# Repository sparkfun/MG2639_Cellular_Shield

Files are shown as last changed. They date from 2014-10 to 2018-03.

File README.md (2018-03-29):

**Note:Retired Product**
This product has been retired from our catalog and is no longer for sale. This page is made available for those looking for datasheets and the simply curious.

SparkFun MG2639 Cellular Shield
=========================

SparkFun MG2639 Cellular Shield (https://www.sparkfun.com/products/13120)

[*SparkFun MG2639 Cellular Shield (CEL-13120)*](https://www.sparkfun.com/products/13120)

The SparkFun MG2639 Cellular shield is an Arduino compatible shield that gives the user access to the MG2639_V3 GSM+GPS module. The module is capable of accquiring a GPS location as well as communication with GSM networks all over the world. Phonecalls can be made, texts sent, and data pushed to and read from web pages. All the supporting circuitry is provided including translation from 2.8V of the module to a user selectable 3.3V or 5V.

The main interface is two software serial ports.

Power can be provided either from the Arduino board's VIN or from an external battery such as a lithium polymer.

Repository Contents
-------------------

* **/Firmware** - Example sketches that work without the Arduino library.
* **/Hardware** - Schematic and PCB layout for the shield. Also includes an eagle library containing the various custom footprints for this shield. Specifically the MG2639 footprint.
* **/Documentation** - The AT command set, hardware guide, and various other datasheets.
* **/Libraries** - The SparkFun MG2639 Cellular Shield library.
* **/Production** - Production panel files.
* **[Hookup Guide](https://learn.sparkfun.com/tutorials/retired---mg2639-cellular-shield-hookup-guide)** - To get started using the MG2639 Cellular Shield, check out our tutorial!

License Information
-------------------
The hardware is released under [CERN Open Hardware License 1.2](http://www.ohwr.org/attachments/2388/cern_ohl_v_1_2.txt).
The code is beerware; if you see me (or any other SparkFun employee) at the local, and you've found our code helpful, please buy us a round!

Distributed as-is; no warranty is given.

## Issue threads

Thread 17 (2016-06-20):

Arduino 1.6.7 warning

i-make-robots, 2016-06-20:
WARNING: Category '' in library SparkFun MG2639 CellShield is not valid. Setting to 'Uncategorized'

couilloux, 2016-09-17:
I have the same issue when I try the simple MG2639_GetInfo.

Any suggestion?

loricrotser, 2018-03-29:
Hello!

Since we have retired this product, I'm closing this issue. If you still need help with this product, you can also check in our forums [here](https://forum.sparkfun.com/).

Please do let us know if you have any more questions.

Thank you!

Closed 2018-03-29.

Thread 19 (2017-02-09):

HTTP REQUEST

n3mu, 2017-02-09:
So I try to edit the sample codes to " GET /test.php?fn=test HTTP/1.1\nHost: mysite.com\n\n"
It runs but it doesn't pass the 'fn' and I also try POST with HTTP headers and again it doesn't work, Anyone who have try to do HTTTP request before?

loricrotser, 2018-03-29:
Hello!

Since we have retired this product, I'm closing this issue. If you still need help with this product, you can also check in our forums [here](https://forum.sparkfun.com/).

Please do let us know if you have any more questions.

Thank you!

Closed 2018-03-29.

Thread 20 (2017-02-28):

BUG: Missing "return"

tatobari, 2017-02-28:
Line 108 of `MG2639_Cellular_Shield/Libraries/Arduino/src/SFE_MG2639_CellShield.cpp` should be:

`return begin(TARGET_BAUD_RATE);`

Instead of:

`begin(TARGET_BAUD_RATE);`

Otherwise, you can't know if the communication with the shield was successful because `0` is returned if nothing is specified.

loricrotser, 2018-03-29:
Hello!

Since we have retired this product, I'm closing this issue. If you still need help with this product, you can also check in our forums [here](https://forum.sparkfun.com/).

Please do let us know if you have any more questions.

Thank you!

Closed 2018-03-29.

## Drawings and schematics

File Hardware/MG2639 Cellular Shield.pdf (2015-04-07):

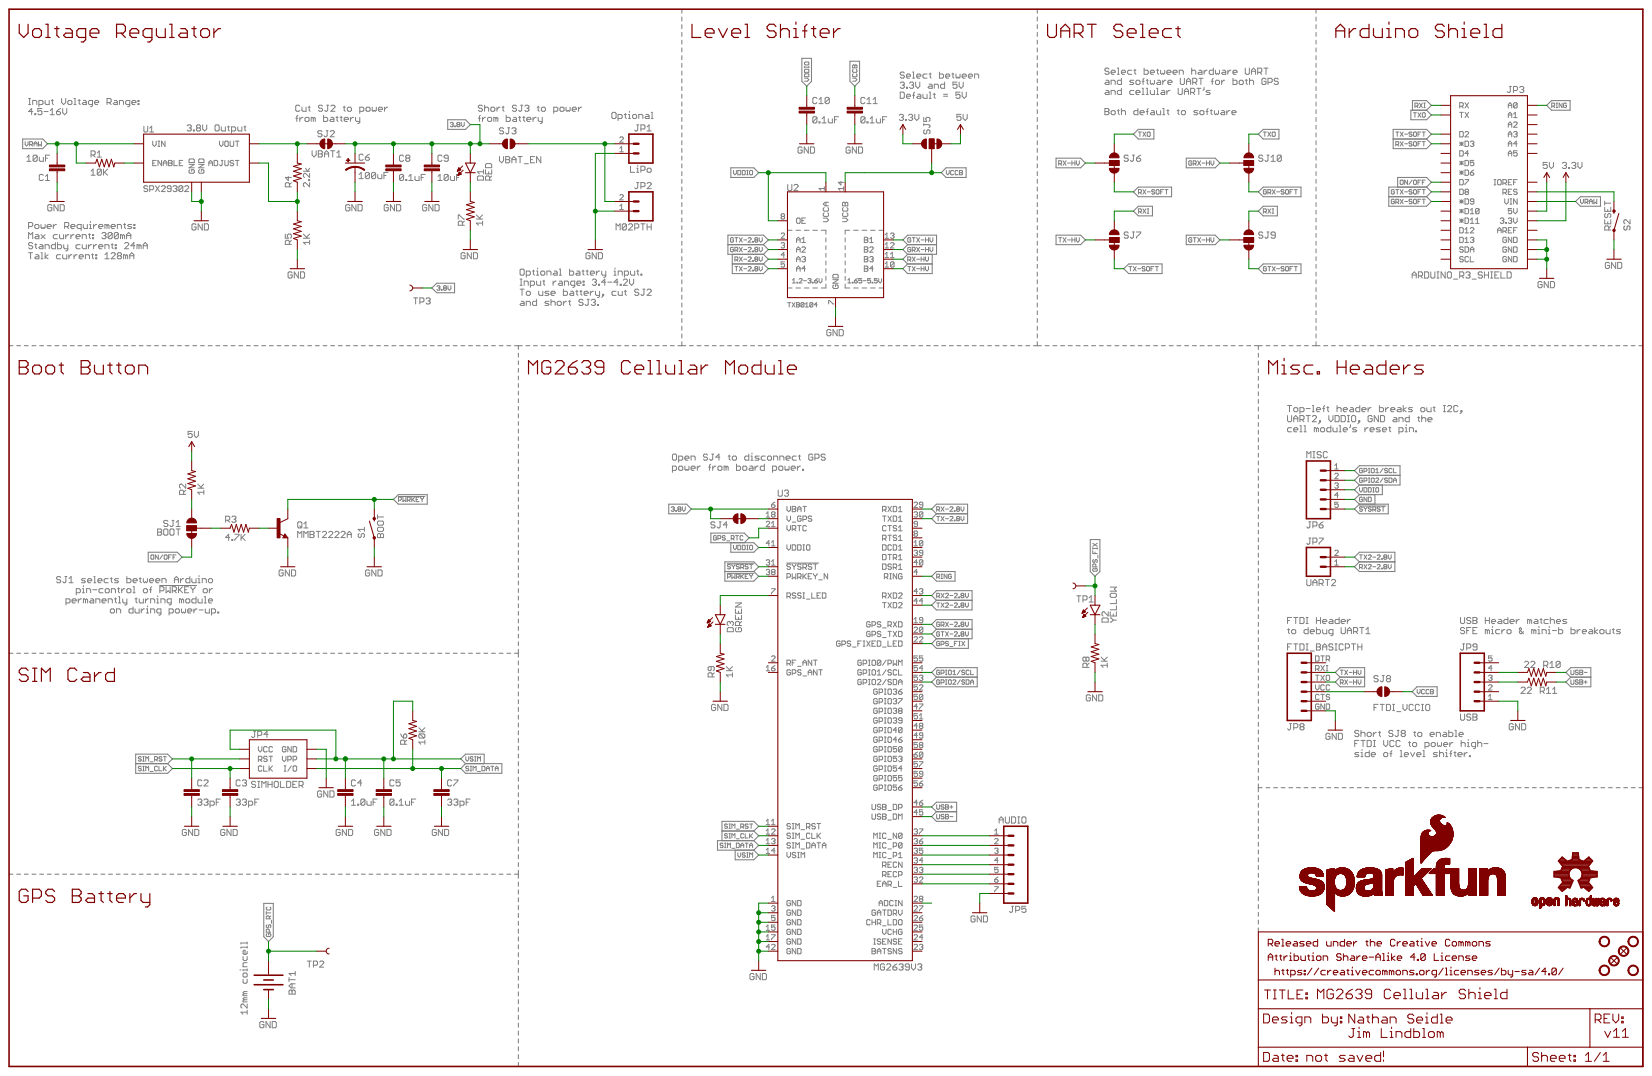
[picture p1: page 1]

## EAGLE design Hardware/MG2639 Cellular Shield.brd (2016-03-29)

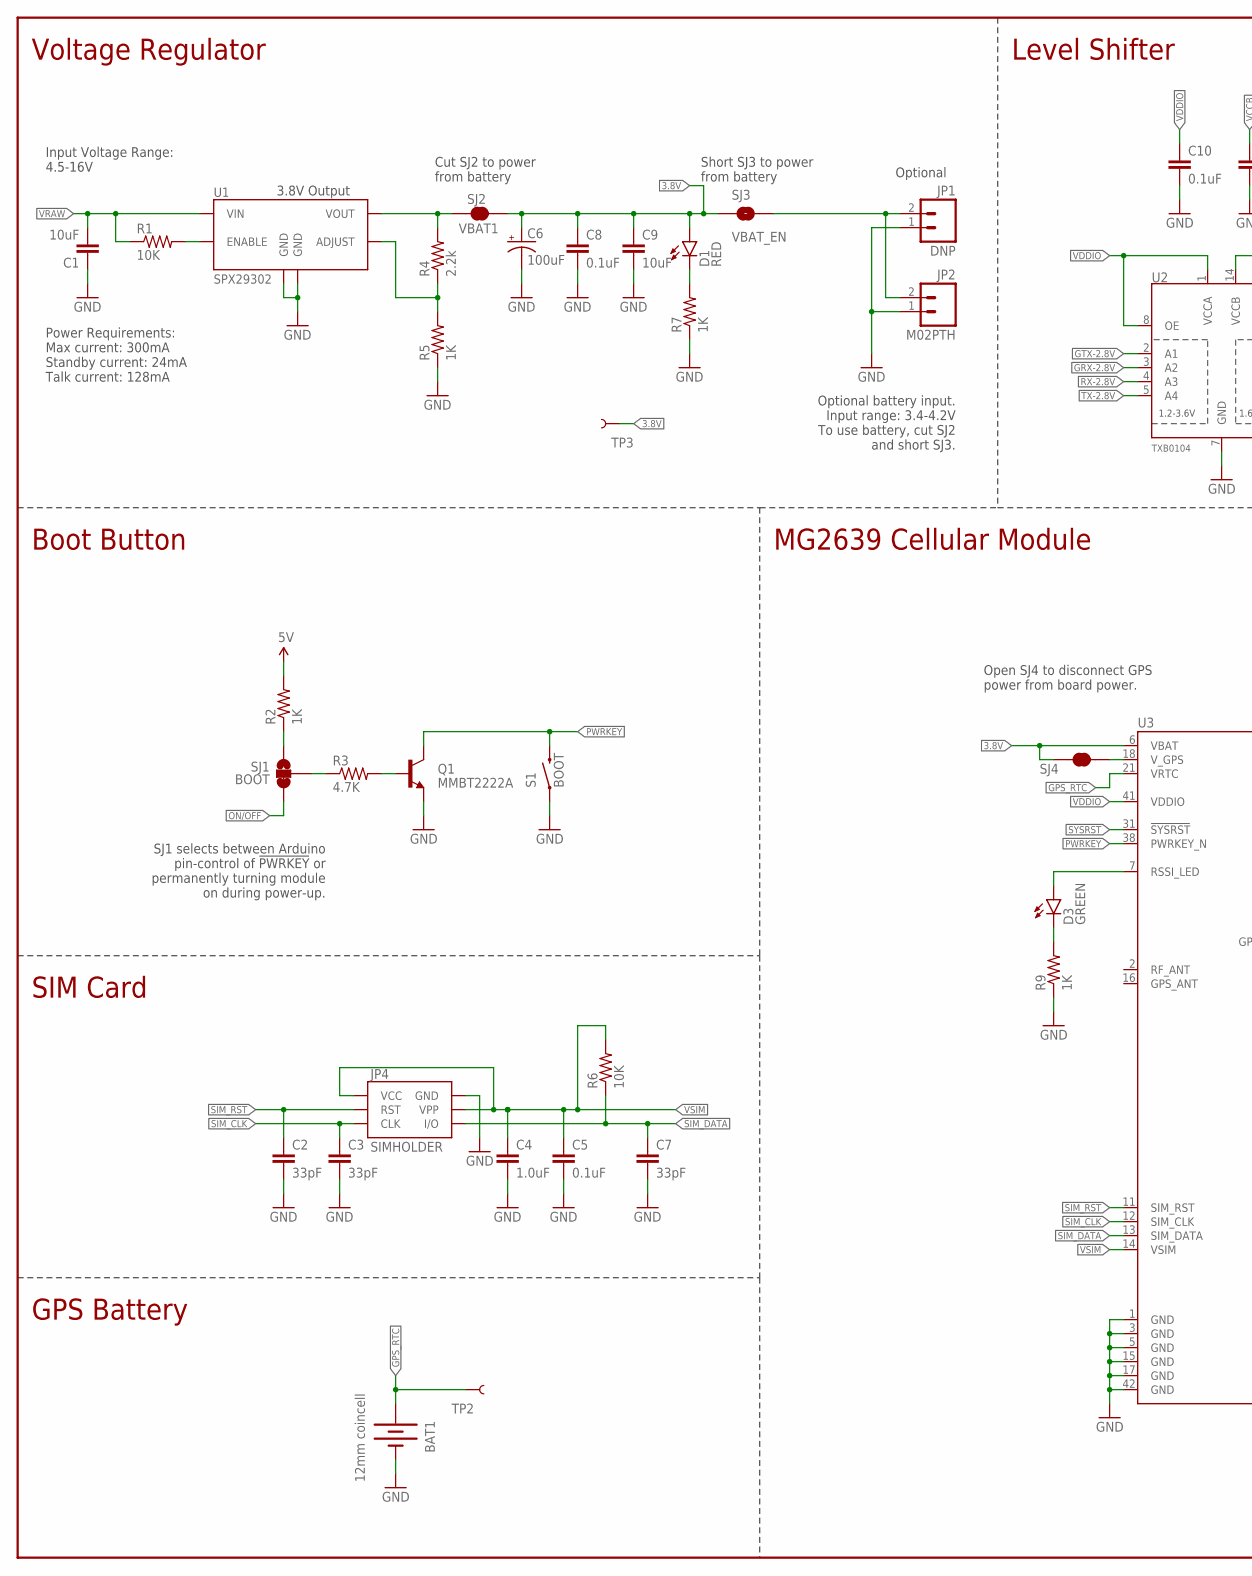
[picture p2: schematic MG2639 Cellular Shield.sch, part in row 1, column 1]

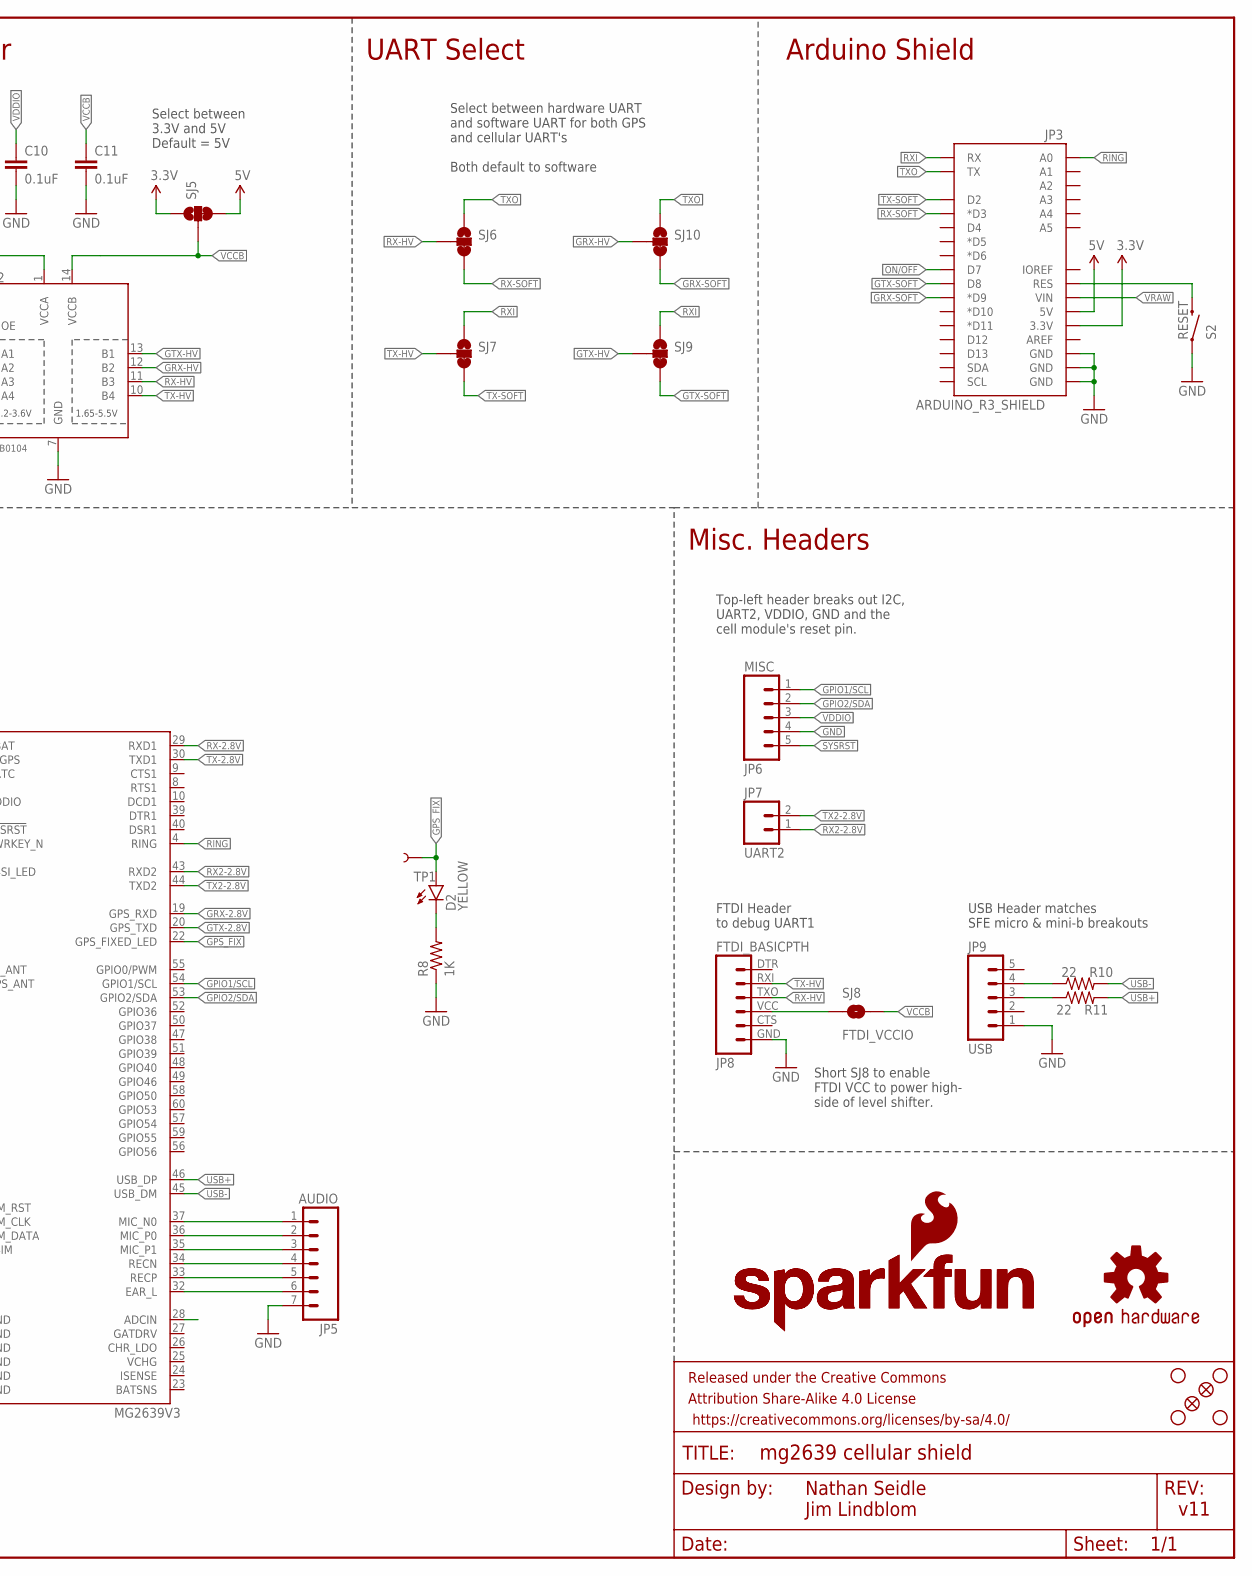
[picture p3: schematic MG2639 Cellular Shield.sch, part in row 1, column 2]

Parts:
BAT1: 12mm coincell; BATTCON_12MM
C1, C9: 10uF; 1210
C2, C3, C7: 33pF; 0603-CAP
C4: 1.0uF; 0603-CAP
C5, C8, C10, C11: 0.1uF; 0603-CAP
C6: 100uF; EIA7343
D1: RED; LED-1206
D2: YELLOW; LED-1206
D3: GREEN; LED-1206
FID1, FID2: FIDUCIAL1X2; FIDUCIAL-1X2
FRAME1: FRAME-LEDGER; CREATIVE_COMMONS
JP1: DNP; JST-2-PTH
JP2: M02PTH; 1X02
JP3: ARDUINO_R3_SHIELD; UNO_R3_SHIELD_NOLABELS
JP4: SIMHOLDER
JP5: AUDIO; 1X07
JP6: MISC; 1X05
JP7: UART2; 1X02
JP8: FTDI_BASICPTH; FTDI_BASIC
JP9: USB; 1X05
LOGO1: SFE_LOGO_NAME.1_INCH; SFE_LOGO_NAME_.1
LOGO2: SFE_LOGO_NAME_FLAME.2_INCH; SFE_LOGO_NAME_FLAME_.2
LOGO3: OSHW-LOGOS; OSHW-LOGO-S
Q1: MMBT2222A; SOT23-3
R1, R6: 10K; 0603-RES
R2, R5, R7, R8, R9: 1K; 0603-RES
R3: 4.7K; 0603
R4: 2.2k; 0603-RES
R10, R11: 22; 0603-RES
S1: BOOT; TACTILE-SWITCH-SMD
S2: RESET; TACTILE-SWITCH-SMD
SJ1: BOOT; PAD-JUMPER-3-2OF3_NC_BY_TRACE_YES_SILK_FULL_BOX
SJ2: VBAT1; PAD-JUMPER-2-NC_BY_TRACE_YES_SILK
SJ3: VBAT_EN; PAD-JUMPER-2-NO_YES_SILK
SJ4: JUMPER-PAD-2-NC_BY_TRACE; PAD-JUMPER-2-NC_BY_TRACE_YES_SILK
SJ5, SJ6, SJ7, SJ9, SJ10: JUMPER-PAD-3-2OF3_NC_BY_TRACE; PAD-JUMPER-3-2OF3_NC_BY_TRACE_YES_SILK_FULL_BOX
SJ8: FTDI_VCCIO; PAD-JUMPER-2-NO_YES_SILK
STANDOFF1, STANDOFF2, STANDOFF3, STANDOFF4: STAND-OFF
TP1, TP2, TP3: TEST-POINT3X5; PAD.03X.05
U1: SPX29302; Q5-DD_SPX29300
U2: TXB0104; SO14
U3: MG2639V3; MG2639

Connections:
3.3V: JP3.3.3V, SJ5.1
3.8V: C6.A (+), C8.1, C9.1, D1.A, SJ2.2, SJ3.1, SJ4.1, TP3.P$1, U3.6 (VBAT)
5V: JP3.5V, R2.2, SJ5.3
!PWRKEY: Q1.3 (C), S1.3 (2), U3.38 (PWRKEY_N)
!SYSRST: JP6.5, U3.31 (!SYSRST)
ADCIN: U3.28 (ADCIN)
ADJUST: R4.1, R5.2, U1.5 (ADJUST)
EAR_L: JP5.6, U3.32 (EAR_L)
GND: BAT1.GND (-), C1.1, C2.2, C3.2, C4.2, C5.2, C6.C (-), C7.2, C8.2, C9.2, C10.2, C11.2, JP1.1, JP2.1, JP3.GND@0 (GND), JP3.GND@1 (GND), JP3.GND@2 (GND), JP4.C5 (GND), JP5.7, JP6.4, JP8.GND (6), JP9.1, Q1.2 (E), R5.1, R7.1, R8.1, R9.1, S1.1, S2.1, U1.3 (GND), U1.6 (GND), U2.7 (GND), U3.1 (GND), U3.3 (GND), U3.5 (GND), U3.15 (GND), U3.17 (GND), U3.42 (GND)
GPIO1/SCL: JP6.1, U3.54 (GPIO1/SCL)
GPIO2/SDA: JP6.2, U3.53 (GPIO2/SDA)
GPS_FIX: D2.A, TP1.P$1, U3.22 (GPS_FIXED_LED)
GPS_RTC: BAT1.PWR@1 (+), TP2.P$1, U3.21 (VRTC)
GRX-2.8V: U2.3 (A2), U3.19 (GPS_RXD)
GRX-HV: SJ10.2, U2.12 (B2)
GRX-SOFT: JP3.D9 (*D9), SJ10.3
GTX-2.8V: U2.2 (A1), U3.20 (GPS_TXD)
GTX-HV: SJ9.2, U2.13 (B1)
GTX-SOFT: JP3.D8, SJ9.3
MIC_N0: JP5.1, U3.37 (MIC_N0)
MIC_P0: JP5.2, U3.36 (MIC_P0)
MIC_P1: JP5.3, U3.35 (MIC_P1)
unnamed: R1.2, U1.1 (ENABLE)
unnamed: JP9.4, R10.1
unnamed: Q1.1 (B), R3.2
unnamed: R4.2, SJ2.1, U1.4 (VOUT)
unnamed: R3.1, SJ1.2
unnamed: R2.1, SJ1.1
unnamed: D3.A, U3.7 (RSSI_LED)
unnamed: D3.C, R9.2
unnamed: D2.C, R8.2
unnamed: JP9.3, R11.1
unnamed: JP8.VCC (4), SJ8.1
unnamed: JP1.2, JP2.2, SJ3.2
unnamed: D1.C, R7.2
ON/OFF: JP3.D7, SJ1.3
RECN: JP5.4, U3.34 (RECN)
RECP: JP5.5, U3.33 (RECP)
RESET: JP3.RES, S2.3 (2)
RING: JP3.A0, U3.4 (RING)
RX2-2.8V: JP7.1, U3.43 (RXD2)
RX-2.8V: U2.4 (A3), U3.29 (RXD1)
RX-HV: JP8.TXO (3), SJ6.2, U2.11 (B3)
RX-SOFT: JP3.D3 (*D3), SJ6.3
RXI: JP3.RX, SJ7.1, SJ9.1
SIM_CLK: C3.1, JP4.C3 (CLK), U3.12 (SIM_CLK)
SIM_DATA: C7.1, JP4.C7 (I/O), R6.1, U3.13 (SIM_DATA)
SIM_RST: C2.1, JP4.C2 (RST), U3.11 (SIM_RST)
TX2-2.8V: JP7.2, U3.44 (TXD2)
TX-2.8V: U2.5 (A4), U3.30 (TXD1)
TX-HV: JP8.RXI (2), SJ7.2, U2.10 (B4)
TX-SOFT: JP3.D2, SJ7.3
TXO: JP3.TX, SJ6.1, SJ10.1
USB+: R11.2, U3.46 (USB_DP)
USB-: R10.2, U3.45 (USB_DM)
VCCB: C11.1, SJ5.2, SJ8.2, U2.14 (VCCB)
VCHG: U3.25 (VCHG)
VDDIO: C10.1, JP6.3, U2.1 (VCCA), U2.8 (OE), U3.41 (VDDIO)
VRAW: C1.2, JP3.VIN, R1.1, U1.2 (VIN)
VSIM: C4.1, C5.1, JP4.C1 (VCC), JP4.C6 (VPP), R6.2, U3.14 (VSIM)
V_GPS: SJ4.2, U3.18 (V_GPS)

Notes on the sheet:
3.8V Output
Select between 3.3V and 5V Default = 5V
Select between hardware UART and software UART for both GPS and cellular UART's Both default to software
Cut SJ2 to power from battery
Optional
Nathan Seidle Jim Lindblom
Open SJ4 to disconnect GPS power from board power.
v11
Voltage Regulator
Level Shifter
UART Select
Arduino Shield
Misc. Headers
MG2639 Cellular Module
Boot Button
SIM Card
GPS Battery
FTDI Header to debug UART1
USB Header matches SFE micro & mini-b breakouts
Top-left header breaks out I2C, UART2, VDDIO, GND and the cell module's reset pin.
Short SJ3 to power from battery
Optional battery input. Input range: 3.4-4.2V To use battery, cut SJ2 and short SJ3.
Input Voltage Range: 4.5-16V
Power Requirements: Max current: 300mA Standby current: 24mA Talk current: 128mA
Short SJ8 to enable FTDI VCC to power high- side of level shifter.
SJ1 selects between Arduino pin-control of !PWRKEY! or permanently turning module on during power-up.

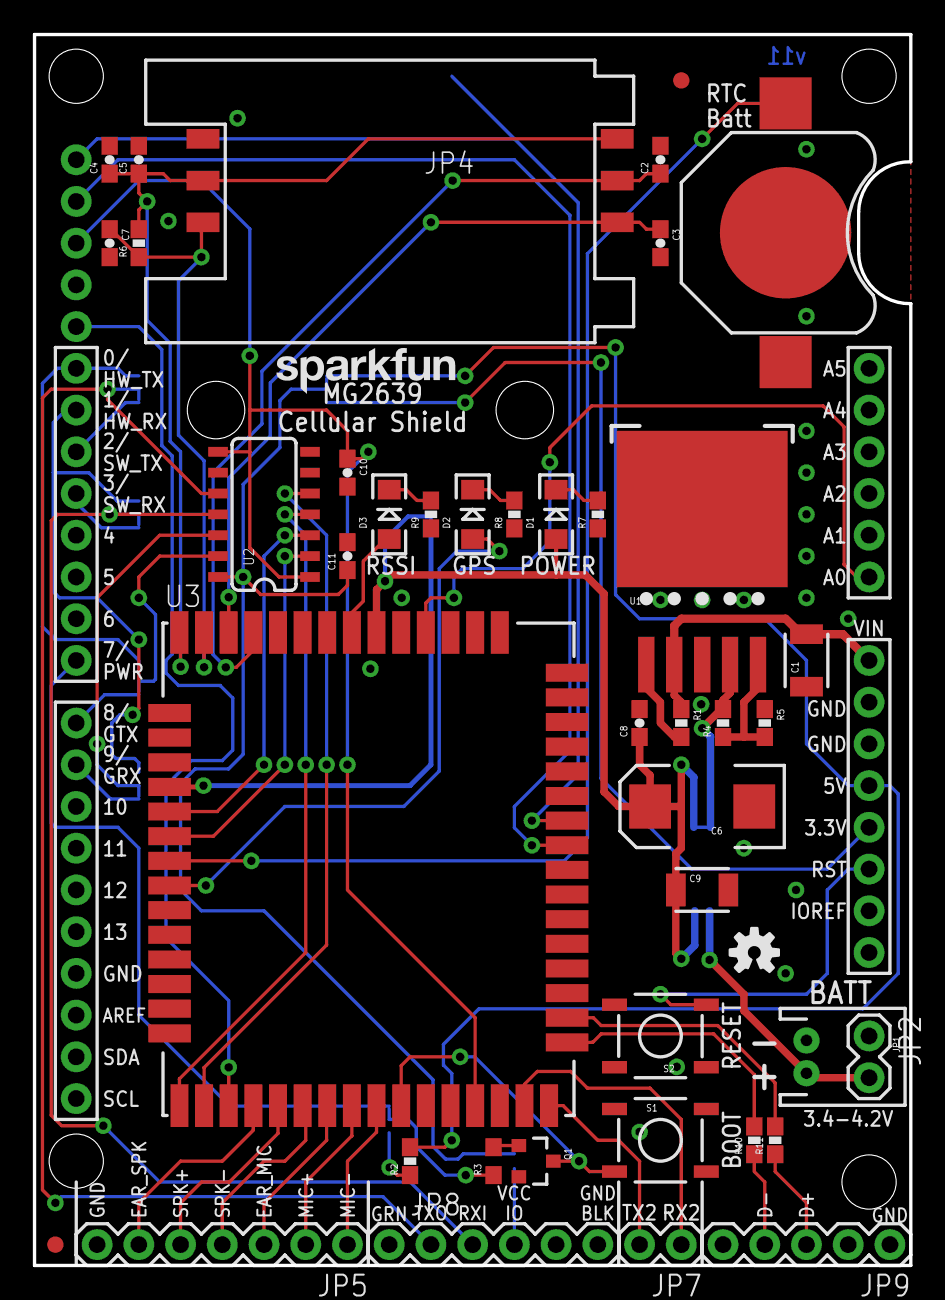
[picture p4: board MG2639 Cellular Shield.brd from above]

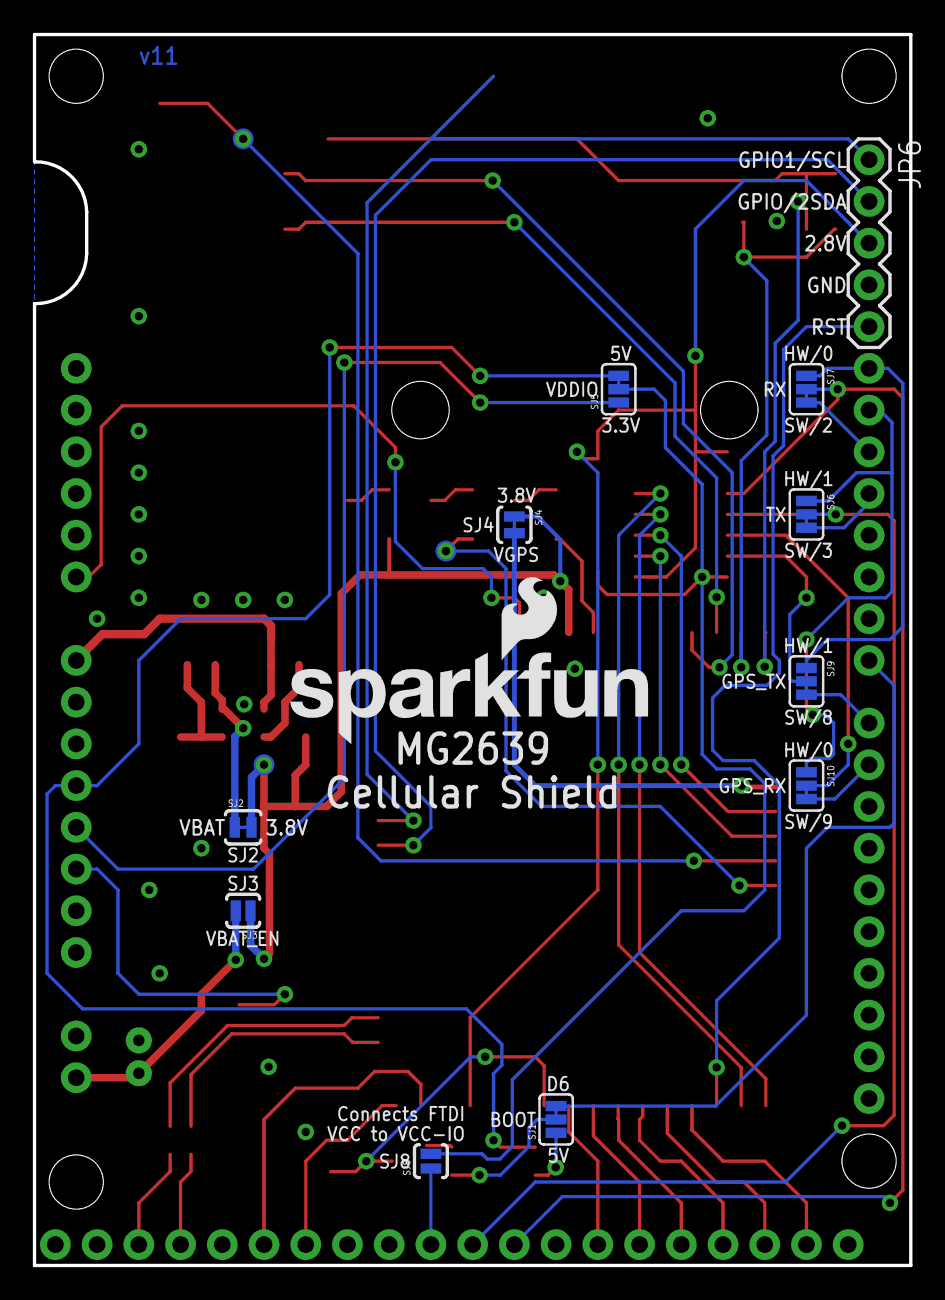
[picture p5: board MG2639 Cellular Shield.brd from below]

Board: 2 copper layers, 53.3 x 74.9 mm, 64 parts (15 on the bottom side), 59 nets.

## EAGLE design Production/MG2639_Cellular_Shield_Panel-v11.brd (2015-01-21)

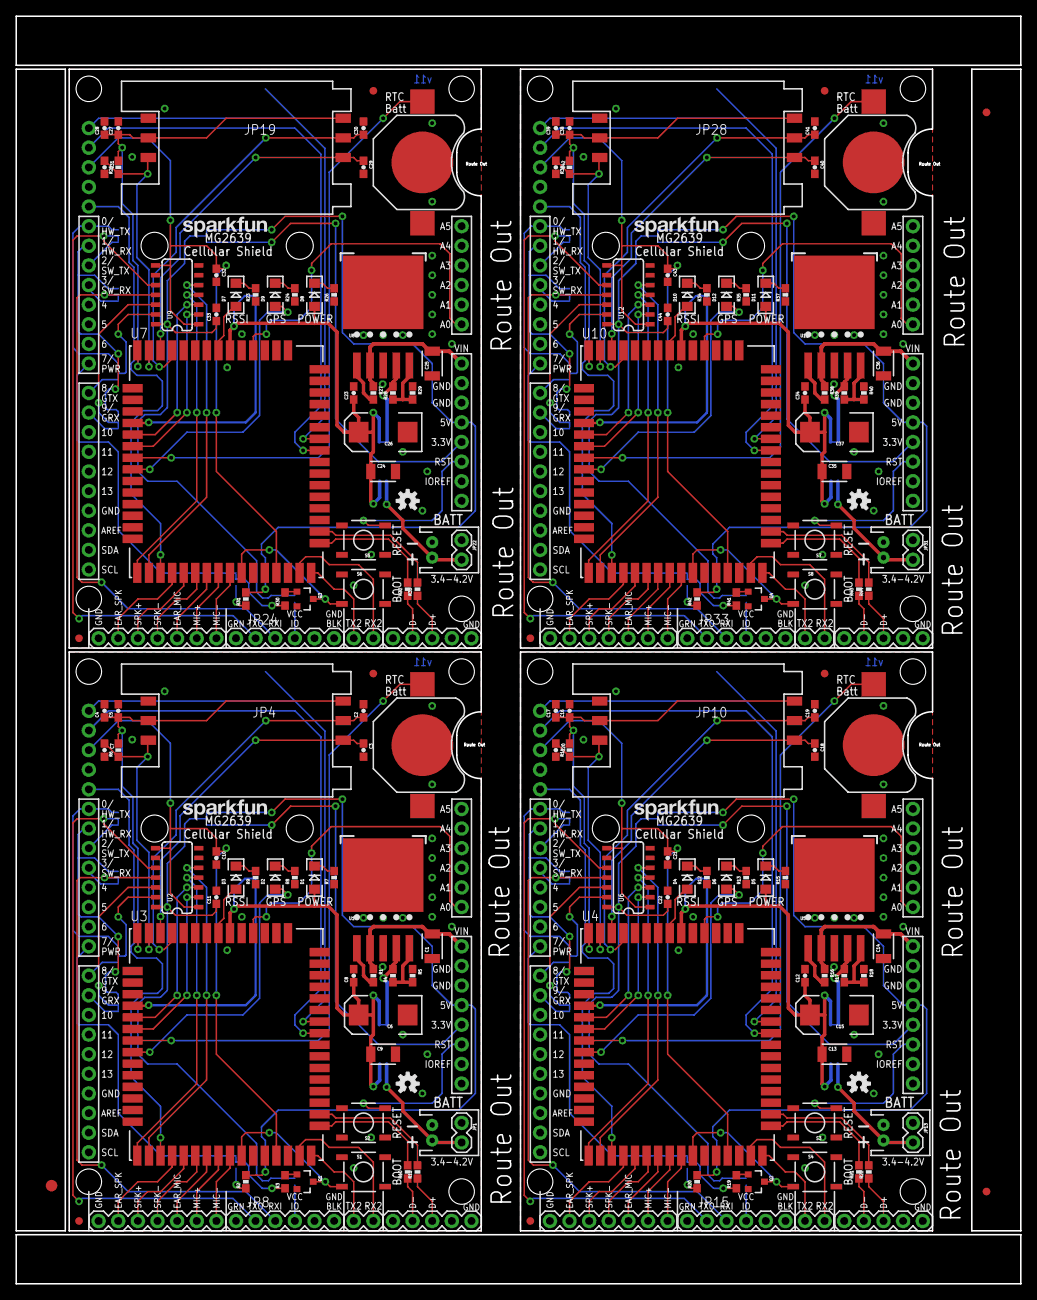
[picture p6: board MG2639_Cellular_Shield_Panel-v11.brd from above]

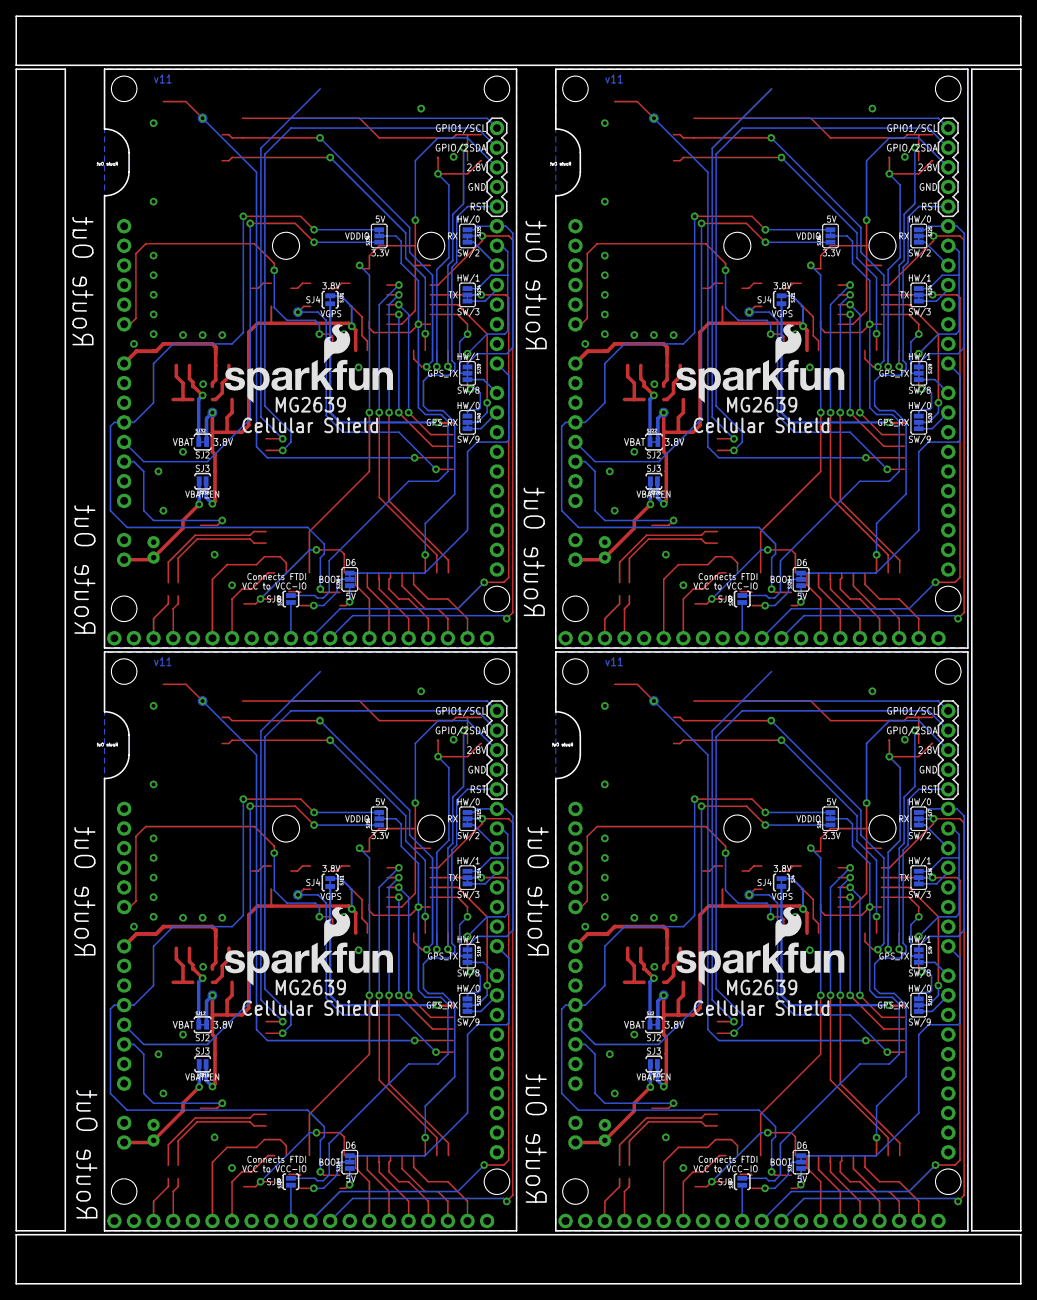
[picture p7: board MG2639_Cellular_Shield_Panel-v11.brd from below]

Board: 2 copper layers, 130.0 x 164.1 mm, 255 parts (60 on the bottom side), 236 nets.

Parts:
BAT1, BAT2, BAT3, BAT4: 12mm coincell; BATTCON_12MM
C1, C9, C13, C14, C24, C25, C35, C36: 10uF; 1210
C2, C3, C7, C18, C19, C20, C29, C30, C31, C40, C41, C42: 33pF; 0603-CAP
C4, C17, C28, C39: 1.0uF; 0603-CAP
C5, C8, C10, C11, C12, C16, C21, C22, C23, C27, C32, C33, C34, C38, C43, C44: 0.1uF; 0603-CAP
C6, C15, C26, C37: 100uF; EIA7343
D1, D5, D8, D11: RED; LED-1206
D2, D6, D9, D12: YELLOW; LED-1206
D3, D4, D7, D10: GREEN; LED-1206
E$1: FIDUCIAL-1.5X3
E$4, E$5: FIDUCIAL-1X2
FID1, FID2, FID3, FID4, FID5, FID6, FID7, FID8: FIDUCIAL1X2; FIDUCIAL-1X2
JP1, JP13, JP22, JP31: LiPo; JST-2-PTH
JP2, JP16, JP25, JP34: M02PTH; 1X02
JP3, JP11, JP20, JP29: ARDUINO_R3_SHIELD; UNO_R3_SHIELD_NOLABELS
JP4, JP10, JP19, JP28: SIMHOLDER
JP5, JP12, JP21, JP30: AUDIO; 1X07
JP6, JP18, JP27, JP36: MISC; 1X05
JP7, JP17, JP26, JP35: UART2; 1X02
JP8, JP15, JP24, JP33: FTDI_BASICPTH; FTDI_BASIC
JP9, JP14, JP23, JP32: USB; 1X05
LOGO1, LOGO6, LOGO9, LOGO12: SFE_LOGO_NAME.1_INCH; SFE_LOGO_NAME_.1
LOGO2, LOGO5, LOGO8, LOGO11: SFE_LOGO_NAME_FLAME.2_INCH; SFE_LOGO_NAME_FLAME_.2
LOGO3, LOGO4, LOGO7, LOGO10: OSHW-LOGOS; OSHW-LOGO-S
Q1, Q2, Q3, Q4: MMBT2222A; SOT23-3
R1, R6, R14, R16, R25, R27, R36, R38: 10K; 0603-RES
R2, R5, R7, R8, R9, R12, R13, R15, R18, R20, R23, R24, R26, R29, R31, R34, R35, R37, R40, R42: 1K; 0603-RES
R3, R19, R30, R41: 4.7K; 0603
R4, R17, R28, R39: 2.2k; 0603-RES
R10, R11, R21, R22, R32, R33, R43, R44: 22; 0603-RES
S1, S4, S6, S8: BOOT; TACTILE-SWITCH-SMD
S2, S3, S5, S7: RESET; TACTILE-SWITCH-SMD
SJ1, SJ13, SJ23, SJ33: BOOT; PAD-JUMPER-3-2OF3_NC_BY_TRACE_YES_SILK_FULL_BOX
SJ2, SJ12, SJ22, SJ32: VBAT1; PAD-JUMPER-2-NC_BY_TRACE_YES_SILK
SJ3, SJ18, SJ28, SJ38: VBAT_EN; PAD-JUMPER-2-NO_YES_SILK
SJ4, SJ11, SJ21, SJ31: PAD-JUMPER-2-NC_BY_TRACE_YES_SILK
SJ5, SJ6, SJ7, SJ9, SJ10, SJ14, SJ15, SJ16, SJ19, SJ20, SJ24, SJ25, SJ26, SJ29, SJ30, SJ34, SJ35, SJ36, SJ39, SJ40: PAD-JUMPER-3-2OF3_NC_BY_TRACE_YES_SILK_FULL_BOX
SJ8, SJ17, SJ27, SJ37: FTDI_VCCIO; PAD-JUMPER-2-NO_YES_SILK
STANDOFF1, STANDOFF2, STANDOFF3, STANDOFF4, STANDOFF5, STANDOFF6, STANDOFF7, STANDOFF8, STANDOFF9, STANDOFF10, STANDOFF11, STANDOFF12, STANDOFF13, STANDOFF14, STANDOFF15, STANDOFF16: STAND-OFF
TP1, TP2, TP3, TP4, TP5, TP6, TP7, TP8, TP9, TP10, TP11, TP12: PAD.03X.05
U1, U5, U8, U11: SPX29302; Q5-DD_SPX29300
U2, U6, U9, U12: TXB0104; SO14
U3, U4, U7, U10: MG2639V3; MG2639

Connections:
3.3V: JP3.3.3V, SJ5.1
3.3V1: JP11.3.3V, SJ16.1
3.3V2: JP20.3.3V, SJ26.1
3.3V3: JP29.3.3V, SJ36.1
3.8V: C6.A, C8.1, C9.1, D1.A, SJ2.2, SJ3.1, SJ4.1, TP3.P$1, U3.6
3.8V1: C12.1, C13.1, C15.A, D5.A, SJ11.1, SJ12.2, SJ18.1, TP6.P$1, U4.6
3.8V2: C23.1, C24.1, C26.A, D8.A, SJ21.1, SJ22.2, SJ28.1, TP9.P$1, U7.6
3.8V3: C34.1, C35.1, C37.A, D11.A, SJ31.1, SJ32.2, SJ38.1, TP12.P$1, U10.6
5V: JP3.5V, R2.2, SJ5.3
5V1: JP11.5V, R20.2, SJ16.3
5V2: JP20.5V, R31.2, SJ26.3
5V3: JP29.5V, R42.2, SJ36.3
!PWRKEY: Q1.3, S1.3, U3.38
!PWRKEY1: Q2.3, S4.3, U4.38
!PWRKEY2: Q3.3, S6.3, U7.38
!PWRKEY3: Q4.3, S8.3, U10.38
!SYSRST: JP6.5, U3.31
!SYSRST1: JP18.5, U4.31
!SYSRST2: JP27.5, U7.31
!SYSRST3: JP36.5, U10.31
ADJUST: R4.1, R5.2, U1.5
ADJUST1: R17.1, R18.2, U5.5
ADJUST2: R28.1, R29.2, U8.5
ADJUST3: R39.1, R40.2, U11.5
EAR_L: JP5.6, U3.32
EAR_L1: JP12.6, U4.32
EAR_L2: JP21.6, U7.32
EAR_L3: JP30.6, U10.32
GND: BAT1.GND, C1.1, C2.2, C3.2, C4.2, C5.2, C6.C, C7.2, C8.2, C9.2, C10.2, C11.2, JP1.1, JP2.1, JP3.GND@0, JP3.GND@1, JP3.GND@2, JP4.C5, JP5.7, JP6.4, JP8.GND, JP9.1, Q1.2, R5.1, R7.1, R8.1, R9.1, S1.1, S2.1, U1.3, U1.6, U2.7, U3.1, U3.3, U3.5, U3.15, U3.17, U3.42
GND1: BAT2.GND, C12.2, C13.2, C14.1, C15.C, C16.2, C17.2, C18.2, C19.2, C20.2, C21.2, C22.2, JP10.C5, JP11.GND@0, JP11.GND@1, JP11.GND@2, JP12.7, JP13.1, JP14.1, JP15.GND, JP16.1, JP18.4, Q2.2, R12.1, R13.1, R15.1, R18.1, S3.1, S4.1, U4.1, U4.3, U4.5, U4.15, U4.17, U4.42, U5.3, U5.6, U6.7
GND2: BAT3.GND, C23.2, C24.2, C25.1, C26.C, C27.2, C28.2, C29.2, C30.2, C31.2, C32.2, C33.2, JP19.C5, JP20.GND@0, JP20.GND@1, JP20.GND@2, JP21.7, JP22.1, JP23.1, JP24.GND, JP25.1, JP27.4, Q3.2, R23.1, R24.1, R26.1, R29.1, S5.1, S6.1, U7.1, U7.3, U7.5, U7.15, U7.17, U7.42, U8.3, U8.6, U9.7
GND3: BAT4.GND, C34.2, C35.2, C36.1, C37.C, C38.2, C39.2, C40.2, C41.2, C42.2, C43.2, C44.2, JP28.C5, JP29.GND@0, JP29.GND@1, JP29.GND@2, JP30.7, JP31.1, JP32.1, JP33.GND, JP34.1, JP36.4, Q4.2, R34.1, R35.1, R37.1, R40.1, S7.1, S8.1, U10.1, U10.3, U10.5, U10.15, U10.17, U10.42, U11.3, U11.6, U12.7
GPIO1/SCL: JP6.1, U3.54
GPIO1/SCL1: JP18.1, U4.54
GPIO1/SCL2: JP27.1, U7.54
GPIO1/SCL3: JP36.1, U10.54
GPIO2/SDA: JP6.2, U3.53
GPIO2/SDA1: JP18.2, U4.53
GPIO2/SDA2: JP27.2, U7.53
GPIO2/SDA3: JP36.2, U10.53
GPS_FIX: D2.A, TP1.P$1, U3.22
GPS_FIX1: D6.A, TP4.P$1, U4.22
GPS_FIX2: D9.A, TP7.P$1, U7.22
GPS_FIX3: D12.A, TP10.P$1, U10.22
GPS_RTC: BAT1.PWR@1, TP2.P$1, U3.21
GPS_RTC1: BAT2.PWR@1, TP5.P$1, U4.21
GPS_RTC2: BAT3.PWR@1, TP8.P$1, U7.21
GPS_RTC3: BAT4.PWR@1, TP11.P$1, U10.21
GRX-2.8V: U2.3, U3.19
GRX-2.8V1: U4.19, U6.3
GRX-2.8V2: U7.19, U9.3
GRX-2.8V3: U10.19, U12.3
GRX-HV: SJ10.2, U2.12
GRX-HV1: SJ20.2, U6.12
GRX-HV2: SJ30.2, U9.12
GRX-HV3: SJ40.2, U12.12
GRX-SOFT: JP3.D9, SJ10.3
GRX-SOFT1: JP11.D9, SJ20.3
GRX-SOFT2: JP20.D9, SJ30.3
GRX-SOFT3: JP29.D9, SJ40.3
GTX-2.8V: U2.2, U3.20
GTX-2.8V1: U4.20, U6.2
GTX-2.8V2: U7.20, U9.2
GTX-2.8V3: U10.20, U12.2
GTX-HV: SJ9.2, U2.13
GTX-HV1: SJ19.2, U6.13
GTX-HV2: SJ29.2, U9.13
GTX-HV3: SJ39.2, U12.13
GTX-SOFT: JP3.D8, SJ9.3
GTX-SOFT1: JP11.D8, SJ19.3
GTX-SOFT2: JP20.D8, SJ29.3
GTX-SOFT3: JP29.D8, SJ39.3
MIC_N0: JP5.1, U3.37
MIC_N1: JP12.1, U4.37
MIC_N2: JP21.1, U7.37
MIC_N3: JP30.1, U10.37
MIC_P0: JP5.2, U3.36
MIC_P1: JP5.3, U3.35
MIC_P2: JP12.3, U4.35
MIC_P3: JP12.2, U4.36
MIC_P4: JP21.3, U7.35
MIC_P5: JP21.2, U7.36
MIC_P6: JP30.3, U10.35
MIC_P7: JP30.2, U10.36
unnamed: R1.2, U1.1
unnamed: JP9.4, R10.1
unnamed: Q1.1, R3.2
unnamed: R4.2, SJ2.1, U1.4
unnamed: R3.1, SJ1.2
unnamed: R2.1, SJ1.1
unnamed: D3.A, U3.7
unnamed: D3.C, R9.2
unnamed: D2.C, R8.2
unnamed: JP9.3, R11.1
unnamed: JP8.VCC, SJ8.1
unnamed: JP1.2, JP2.2, SJ3.2
unnamed: D5.C, R15.2
unnamed: R16.2, U5.1
unnamed: Q2.1, R19.2
unnamed: R19.1, SJ13.2
unnamed: D1.C, R7.2
unnamed: D4.A, U4.7
unnamed: D4.C, R12.2
unnamed: D6.C, R13.2
unnamed: R17.2, SJ12.1, U5.4
unnamed: R20.1, SJ13.1
unnamed: JP14.4, R21.1
unnamed: JP14.3, R22.1
unnamed: JP15.VCC, SJ17.1
unnamed: JP13.2, JP16.2, SJ18.2
unnamed: D8.C, R26.2
unnamed: R27.2, U8.1
unnamed: Q3.1, R30.2
unnamed: R30.1, SJ23.2
unnamed: D7.A, U7.7
unnamed: D7.C, R23.2
unnamed: D9.C, R24.2
unnamed: R28.2, SJ22.1, U8.4
unnamed: R31.1, SJ23.1
unnamed: JP23.4, R32.1
unnamed: JP23.3, R33.1
unnamed: JP24.VCC, SJ27.1
unnamed: JP22.2, JP25.2, SJ28.2
unnamed: D11.C, R37.2
unnamed: R38.2, U11.1
unnamed: Q4.1, R41.2
unnamed: R41.1, SJ33.2
unnamed: D10.A, U10.7
unnamed: D10.C, R34.2
unnamed: D12.C, R35.2
unnamed: R39.2, SJ32.1, U11.4
unnamed: R42.1, SJ33.1
unnamed: JP32.4, R43.1
unnamed: JP32.3, R44.1
unnamed: JP33.VCC, SJ37.1
unnamed: JP31.2, JP34.2, SJ38.2
ON/OFF: JP3.D7, SJ1.3
ON/OFF1: JP11.D7, SJ13.3
ON/OFF2: JP20.D7, SJ23.3
ON/OFF3: JP29.D7, SJ33.3
RECN: JP5.4, U3.34
RECN1: JP12.4, U4.34
RECN2: JP21.4, U7.34
RECN3: JP30.4, U10.34
RECP: JP5.5, U3.33
RECP1: JP12.5, U4.33
RECP2: JP21.5, U7.33
RECP3: JP30.5, U10.33
RESET: JP3.RES, S2.3
RESET1: JP11.RES, S3.3
RESET2: JP20.RES, S5.3
RESET3: JP29.RES, S7.3
RING: JP3.A0, U3.4
RING1: JP11.A0, U4.4
RING2: JP20.A0, U7.4
RING3: JP29.A0, U10.4
RX2-2.8V: JP7.1, U3.43
RX2-2.8V1: JP17.1, U4.43
RX2-2.8V2: JP26.1, U7.43
RX2-2.8V3: JP35.1, U10.43
RX-2.8V: U2.4, U3.29
RX-2.8V1: U4.29, U6.4
RX-2.8V2: U7.29, U9.4
RX-2.8V3: U10.29, U12.4
RX-HV: JP8.TXO, SJ6.2, U2.11
RX-HV1: JP15.TXO, SJ14.2, U6.11
RX-HV2: JP24.TXO, SJ24.2, U9.11
RX-HV3: JP33.TXO, SJ34.2, U12.11
RX-SOFT: JP3.D3, SJ6.3
RX-SOFT1: JP11.D3, SJ14.3
RX-SOFT2: JP20.D3, SJ24.3
RX-SOFT3: JP29.D3, SJ34.3
RXI: JP3.RX, SJ7.1, SJ9.1
RXI1: JP11.RX, SJ15.1, SJ19.1
RXI2: JP20.RX, SJ25.1, SJ29.1
RXI3: JP29.RX, SJ35.1, SJ39.1
SIM_CLK: C3.1, JP4.C3, U3.12
SIM_CLK1: C18.1, JP10.C3, U4.12
SIM_CLK2: C29.1, JP19.C3, U7.12
SIM_CLK3: C40.1, JP28.C3, U10.12
SIM_DATA: C7.1, JP4.C7, R6.1, U3.13
SIM_DATA1: C20.1, JP10.C7, R14.1, U4.13
SIM_DATA2: C31.1, JP19.C7, R25.1, U7.13
SIM_DATA3: C42.1, JP28.C7, R36.1, U10.13
SIM_RST: C2.1, JP4.C2, U3.11
SIM_RST1: C19.1, JP10.C2, U4.11
SIM_RST2: C30.1, JP19.C2, U7.11
SIM_RST3: C41.1, JP28.C2, U10.11
TX2-2.8V: JP7.2, U3.44
TX2-2.8V1: JP17.2, U4.44
TX2-2.8V2: JP26.2, U7.44
TX2-2.8V3: JP35.2, U10.44
TX-2.8V: U2.5, U3.30
TX-2.8V1: U4.30, U6.5
TX-2.8V2: U7.30, U9.5
TX-2.8V3: U10.30, U12.5
TX-HV: JP8.RXI, SJ7.2, U2.10
TX-HV1: JP15.RXI, SJ15.2, U6.10
TX-HV2: JP24.RXI, SJ25.2, U9.10
TX-HV3: JP33.RXI, SJ35.2, U12.10
TX-SOFT: JP3.D2, SJ7.3
TX-SOFT1: JP11.D2, SJ15.3
TX-SOFT2: JP20.D2, SJ25.3
TX-SOFT3: JP29.D2, SJ35.3
TXO: JP3.TX, SJ6.1, SJ10.1
TXO1: JP11.TX, SJ14.1, SJ20.1
TXO2: JP20.TX, SJ24.1, SJ30.1
TXO3: JP29.TX, SJ34.1, SJ40.1
USB+: R11.2, U3.46
USB+1: R22.2, U4.46
USB+2: R33.2, U7.46
USB+3: R44.2, U10.46
USB-: R10.2, U3.45
USB-1: R21.2, U4.45
USB-2: R32.2, U7.45
USB-3: R43.2, U10.45
VCCB: C11.1, SJ5.2, SJ8.2, U2.14
VCCB1: C22.1, SJ16.2, SJ17.2, U6.14
VCCB2: C33.1, SJ26.2, SJ27.2, U9.14
VCCB3: C44.1, SJ36.2, SJ37.2, U12.14
VDDIO: C10.1, JP6.3, U2.1, U2.8, U3.41
VDDIO1: C21.1, JP18.3, U4.41, U6.1, U6.8
VDDIO2: C32.1, JP27.3, U7.41, U9.1, U9.8
VDDIO3: C43.1, JP36.3, U10.41, U12.1, U12.8
VRAW: C1.2, JP3.VIN, R1.1, U1.2
VRAW1: C14.2, JP11.VIN, R16.1, U5.2
VRAW2: C25.2, JP20.VIN, R27.1, U8.2
VRAW3: C36.2, JP29.VIN, R38.1, U11.2
VSIM: C4.1, C5.1, JP4.C1, JP4.C6, R6.2, U3.14
VSIM1: C16.1, C17.1, JP10.C1, JP10.C6, R14.2, U4.14
VSIM2: C27.1, C28.1, JP19.C1, JP19.C6, R25.2, U7.14
VSIM3: C38.1, C39.1, JP28.C1, JP28.C6, R36.2, U10.14
V_GPS: SJ4.2, U3.18
V_GPS1: SJ11.2, U4.18
V_GPS2: SJ21.2, U7.18
V_GPS3: SJ31.2, U10.18

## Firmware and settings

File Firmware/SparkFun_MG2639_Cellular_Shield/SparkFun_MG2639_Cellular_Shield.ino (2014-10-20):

/*
 Library and example code for the SparkFun MG2639 Cellular shield.
 By: Nathan Seidle
 SparkFun Electronics
 Date: October 20th, 2014
 License: This code is public domain but you buy me a beer if you use this and we meet someday (Beerware license).
 
The SparkFun MG2639 Cellular shield is an Arduino compatible shield that gives the user access to the MG2639_V3 GSM+GPS module.
 
 The shield is wired in the following way:
 
 Arduino pin RX -> MG2639 TX
 TX -> MG2639 RX
 D2 -> TX (enable with solder jumper SJ3)
 D3 -> RX (enable with solder jumper SJ4)
 D4 -> GPS RX
 D5 -> GPS TX
 D6 -> Cell Reset (pull down 500ms minimum to reset module)
 D7 -> On/Off (Provide 2-5s low pulse to turn on/off module)
 
 NOTE: 
 This shield draws more than most usb ports can provide. Apply external power to prevent erratic rebooting.
 
 TODO:
 Get bulletproof boot sequence with ATOK testing, baud rate setting, and AT&F if nescessary
 
 Solder Jumpers
 SJ1 -> Open to disconnect gps power from board power.
 SJ2 -> Open to free up GPIO pin. If opened, you have to reboot via boot button.
 SJ3 -> Select between hardware UART and software UART. Default = hardware
 SJ4 -> Select between hardware UART and software UART. Default = hardware
 SJ5 -> Select between 3.3v and 5v. Default = 3.3v
 SJ6 -> Cut to power board exclusively from battery.
 
 */

//GPIO declarations
//-=-=-=-=-=-=-=-=-=-=-=-=-=-=-=-=-=-=-=-=-=-=-=-=

byte cellRX = 2; //Listens to the cell module
byte cellTX = 3; //Transmit to the cell module
byte gpsRX = 4; //Listens to the GPS module inside the MG2639
byte gpsTX = 5; //Transmit to the GPS module inside the MG2639
byte cellReset = 6;
byte cellOnOff = 7;

byte trigger = 12; //Used for triggering the logic analyzer

//-=-=-=-=-=-=-=-=-=-=-=-=-=-=-=-=-=-=-=-=-=-=-=-=

#include <SoftwareSerial.h>
SoftwareSerial MG2639(cellRX, cellTX); //RX, TX

//#include <AltSoftSerial.h>
//AltSoftSerial MG2639; //TX is on 9, RX is on 8

const byte MAX_INPUT = 50;
static char incomingText [MAX_INPUT];
static unsigned int input_pos = 0;
byte newlineCount = 0;

void setup()
{
  Serial.begin(9600);
  Serial.println("MG2639 example");

  //pinMode(cellRX, INPUT);
  //pinMode(cellTX, INPUT);
  
  pinMode(cellReset, OUTPUT);
  digitalWrite(cellReset, LOW); //Don't reset

  pinMode(cellOnOff, OUTPUT);
  digitalWrite(cellOnOff, LOW); //Don't turn on at this time
  
  pinMode(trigger, OUTPUT);
  digitalWrite(trigger, LOW);

  //delay(1000);

  if(!initMG2639()) //Set baud rates and bring module online
  {      
    Serial.println("Module failed to respond. Hanging.");
    while(1);
  }
  Serial.println("Module online!");
  
  //MG2639.print("AT+CREG=2\r");
  //delay(100);

  boolean textSent = false;
  
  while(1)
  {
    int rssi = checkSignalStrength();
    Serial.print("RSSI: ");
    Serial.println(rssi, DEC);
  
    //String response = checkIMEI();
    //Serial.print("IMEI: ");
    //Serial.println(response);
    
    checkRegistration();
    
    delay(2000);
    
    if(rssi < 40 && textSent == false)
    {
      textSent = true;
      //sendTextMessage("Hallo world", "3032466316");
      
      digitalWrite(trigger, HIGH);
      
      String response;

      response = sendCommand("+ZPPPOPEN");
      Serial.print("Open GRPS connection: ");
      Serial.println(response);
      
      delay(2000); //ZIP open takes a while
      
      response = sendCommand("+ZIPSETUP=1,204.144.132.37,80");
      Serial.print("Setup IP: ");
      Serial.println(response);

      delay(2000); //ZIP open takes a while

      response = sendCommand("+ZIPSEND=1,18\n\r");
      MG2639.print("GET / HTTP/1.0\n\r\n\r");
      Serial.print("GPRS Status: ");
      Serial.println(response);

      
      
      while(1);





      /*response = sendCommand("+ZPPPSTATUS");
      Serial.print("GPRS Status: ");
      Serial.println(response);*/

      /*String response = sendCommand("+ZIPSETUP=1,data.sparkfun.com,8081");
      Serial.print("Port open: ");
      Serial.print(response);*/

      response = sendCommand("+CGATT=1");
      Serial.print("GPRS Attach: ");
      Serial.println(response);

//      response = sendCommand("+CGDCONT=1, \"IP\",\"CMNET\"");
      response = sendCommand("+CGDCONT=1, \"IP\",\"internet.t-mobile\"");
//      response = sendCommand("+CGDCONT=1, \"IP\",\"internet.t-mobile\"\r\r\nATD*99#"); //That connects?
      Serial.print("GPRS Connect: ");
      Serial.println(response);
      
      delay(1000);

      response = sendCommand("+CGACT=1,1");
      Serial.print("GPRS Activate: ");
      Serial.println(response);
      
      delay(1000); //Can take as long as 700ms

      /*response = sendCommand("+CGCLASS?");
      Serial.print("GPRS Class: ");
      Serial.println(response);*/

//      response = sendCommand("+ZIPSETUP=1,195.34.89.241,21"); //Test Ublox FTP
      response = sendCommand("+ZIPSETUP=1,54.86.132.254,80");
      Serial.print("Setup IP: ");
      Serial.println(response);

      response = sendCommand("+ZPPPSTATUS");
      Serial.print("GPRS Status: ");
      Serial.println(response);


      response = sendCommand("D*99#");      
//      response = sendCommand("D*99***1#");      
      Serial.print("GPRS Connect: ");
      Serial.println(response);
      
      delay(1000);

      MG2639.print("GET / HTTP/1.0\r\nHost: www.google.com User-Agent: Arduino\r\n\r\n");
      
      
      while(1);

      response = sendCommand("D*99#");      
//      response = sendCommand("D*99***1#");      
      Serial.print("GPRS Connect: ");
      Serial.println(response);
      
      //delay(4500);

      delay(100);
      
      MG2639.print("GET / HTTP/1.0\r\nHost: www.google.com User-Agent: Arduino\r\n\r\n");
      
      
      while(1);
      
      
      /*String strToSend = "https://data.sparkfun.com/input/QGoEWpOOw9snOKqbvxzA?private_key=JqnPm4MM5zujmlyM8p1J&test1=8";
      String strLen = String(strToSend.length());
      
      byte ctrlZ = 26;

      String strToSend2 = "AT+ZIPSEND=8081," + strLen + "\r" + strToSend + ctrlZ;
      Serial.print("Test print: ");
      Serial.println(strToSend2);
            
      delay(100);
      //MG2639.print(strToSend2);

      delay(100);*/
      
    }
  }
  

}

void loop()
{


}

//Sends a message to a phone number
//Returns true if successful
//Generally, text messages have a 160 character limit

boolean sendTextMessage(String message, String phoneNumber)
{
  //Put us in text SMS mode
  String response = sendCommand("+CMGF=1");
  Serial.print("CMGF: ");
  Serial.println(response);

  if(response != "OK") return false; //Bail on error
  
  byte ctrlZ = 26;
  
  String toSend = "+CMGS=\"" + phoneNumber + "\"\r" + message + (char)ctrlZ;
  
  Serial.print("toSend: ");
  Serial.println(toSend);

  response = sendCommand(toSend);
  Serial.print("message: ");
  Serial.println(response);

  
}

//Checks network registration
//Example response = "1, 0", or "<mode>, <stat>"
//Returns the status
//0: Not logged on
//1: Logged on
//2: Not logged on, searching for BS(?)
//4: Unknown code
//5: Logged on, roaming
byte checkRegistration()
{
  String response = sendCommand("+CREG?");
  
  Serial.print("CREG: ");
  Serial.println(response);  
}

//Returns the module unique International Mobile Station Equipment Identity
String checkIMEI()
{
  return(sendCommand("+GSN"));
}

//Sends the standard AT command and looks for OK response
boolean checkATOK()
{
  //Send no command, just AT will be sent
  if(sendCommand("") == "OK") return true;

  return false;
}

//Checks the current reception strength of the cellular signal
//Example response is "3, 99" where 3 is the RSSI and 99 is bit the rate (99 = network unavailable)
int checkSignalStrength()
{
  String response = sendCommand("+CSQ");

  //Serial.print("response: ");
  //Serial.println(response);

  String rssiStr, berStr;

  byte commaPosition = response.indexOf(',');
  if(commaPosition != -1)
  {
    rssiStr = response.substring(0, commaPosition);
    berStr = response.substring(commaPosition + 1, response.length());
  }
  else
  {
    //Serial.println("Error: No comma found");
    return(-2);
  }

  int rssi = rssiStr.toInt();
  int ber = berStr.toInt();

  //Serial.print("rssi: ");
  //Serial.println(rssi);
  //Serial.print("ber: ");
  //Serial.println(ber);

  //An RSSI of 99 means the network is unavailable
  return(rssi);
}

//This sends a command and checks that the response is valid (not error)
//This function is not pretty but it works. Improvments are welcomed.
//For each AT command sent, two to three reponses come back. See ATQuery-Response_Example.png for more info

//Response example: "AT+CSQ\r\r\n+CSQ: 4, 99\r\n\r\nOK\r\n"
//We need to strip off the echoed command, check that we got an OK on the 3rd chunk
//And return the 2nd chunk

//Chunk 1: copy/echo of the command
//Chunk 2: The response data or OK or ERROR
//Chunk 3: OK or nothing

#define ERROR_NOCHARACTERS  "NOCHAR"
#define ERROR_COMMAND_STRING_MISMATCH "MISMATCH"
#define ERROR_RESPONSE2  "REPONSE2ERROR"
#define ERROR_RESPONSE3  "REPONSE3ERROR"

String sendCommand(String command)
{
  String firstChunk; //No command should be longer than 20
  String secondChunk; //Not sure but responses can be large
  String thirdChunk; //Should always be 'OK' or empty

  boolean breakFlag = false;
  int newlineCount = 0;

  String strToSend = "AT" + command + "\r"; //Commands get sent with *only* a \r.
  //Adding a \n will cause the parser to break

  Serial.print(F("Sending command: "));
  Serial.println(strToSend);

  while(MG2639.available()) MG2639.read(); //Remove everything in the buffers
  
  MG2639.print(strToSend); //Send this string to the module

  for(byte x = 0 ; x < 100 ; x++)
  {
    if(MG2639.available()) break; //Wait until we have some characters
    delay(1);
  }
    
  delay(55); //We need a few ms at 9600 to get. 15ms works well

  while(breakFlag == false)
  {
    if(MG2639.available() == false) return(ERROR_NOCHARACTERS); //This shouldn't happen

    char incoming = MG2639.read();

    switch(incoming)
    {
    case '\r':
      //We're done!
      breakFlag = true;
      firstChunk += incoming;
      break;

    default:
      firstChunk += incoming;
      break;
    }
  }

  //Serial.print("Chunk1: ");
  //Serial.println(firstChunk);

  //First test
  if(firstChunk != strToSend)
  {
    Serial.print("Chunk1: ");
    Serial.println(firstChunk);
    return(ERROR_COMMAND_STRING_MISMATCH);
  }

  //Reset the variables
  breakFlag = false;
  newlineCount = 0;

  while(breakFlag == false)
  {
    if(MG2639.available() == false) return(ERROR_NOCHARACTERS); //This shouldn't happen

    char incoming = MG2639.read();

    switch(incoming)
    {
    case '\r':
      //Ignore it
      break;

    case '\n':
      newlineCount++;

      if(newlineCount == 1)
      {
        //Ignore it          
      }
      else if(newlineCount == 2)
      {
        //We're done!
        breakFlag = true;
        secondChunk += incoming;
      }
      break;

    default:
      secondChunk += incoming;
      break;
    }
  }

  //Serial.print("Chunk2: ");
  //Serial.println(secondChunk);

  //Second test
  if(secondChunk == "OK\n")
  {
    //We're ok, this command just doesn't return any data
    return("OK"); //Ignore trailing \n
  }
  else if (secondChunk == "ERROR")
  {
    //This might be an error
    return(ERROR_RESPONSE2);
  }

  //Reset the variables
  breakFlag = false;
  newlineCount = 0;

  while(breakFlag == false)
  {
    if(MG2639.available() == false) return(ERROR_NOCHARACTERS); //This shouldn't happen

    char incoming = MG2639.read();

    switch(incoming)
    {
    case '\r':
      //Ignore it
      break;

    case '\n':
      newlineCount++;

      if(newlineCount == 1)
      {
        //Ignore it          
      }
      else if(newlineCount == 2)
      {
        //We're done!
        breakFlag = true;
        //thirdChunk += incoming; //Ignore the final \n
      }
      break;

    default:
      thirdChunk += incoming;
      break;
    }
  }

  if(thirdChunk == "OK")
  {
    //We're so good!

    command.replace("?", ""); //Some commands (+CREG?) use ? but reponses do not have them. This removes the ? from the command

    //Now remove the original command from the response. 
    //For example: +CSQ: 4, 99 should become " 4, 99"
    secondChunk.replace(command + ":", "");

    secondChunk.trim(); //Get rid of any leading white space

    return(secondChunk); //Report this chunk to the caller
  }
  else
  {
    //This is bad. Probably 'Error'
    Serial.print("Chunk 3: ");
    Serial.print(thirdChunk);
    return(ERROR_RESPONSE3);
  }

}

//This transmits the baud rate command at a few different baud rates in
//an attempt to get module down to 9600
//Returns turn if module successfully responded.
boolean initMG2639(void)
{
  //Quick test to see if module is already on and responding to AT commands
  MG2639.begin(9600);
  for(int x = 0 ; x < 5 ; x++)
  {
    if(checkATOK()) return(true);
    delay(100);
  }
  MG2639.end(); //That failed
  
  Serial.println("Turning on module");
  digitalWrite(cellOnOff, HIGH); //Turn on module
  delay(3000);
  digitalWrite(cellOnOff, LOW); //Leave module on

  Serial.println("Module should now be on");  

  MG2639.begin(115200);

  delay(10);

  MG2639.print("AT+IPR=9600\r\n"); //Set baud rate to 9600bps

  delay(10);

  MG2639.end(); //Hang up and go to 9600bps

  MG2639.begin(9600);

  delay(10);

  //Try sending AT 5 times before giving up
  for(int x = 0 ; x < 5 ; x++)
  {
    if(checkATOK()) return(true);
    delay(100);
  }

  return(false);
}

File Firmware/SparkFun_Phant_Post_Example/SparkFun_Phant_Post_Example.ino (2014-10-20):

/*
 Example showing to send a text message and how to receive one using the MG2639
 By: Nathan Seidle
 SparkFun Electronics
 Date: October 12th, 2014
 License: This code is public domain but you buy me a beer if you use this and we meet someday (Beerware license).

 This will send a text message to the cell phone number of your choice. This will give you the phone number of
 the SIM card in your posession. It will also scan for incoming text messages and if you send the module the message
 "turn off water" the example will respond with 'Turning off water!' and you can control GPIOs and such.
 
 Based on examples from www.open-electronics.org
 
 To turn off the extra print statemets comment out DEBUG_ON inside of GSM.h
 
 This assumes the cellular shield is connected to an Uno and has the software serial pins connected to pins 2 and 3
 To change pins for Software Serial see GSM.cpp

*/

#include "MG2639.h"
#include <SoftwareSerial.h>

#include "inetGSM.h"
InetGSM inet;

boolean module_connected = false;

void setup()
{
  Serial.begin(9600);
  Serial.println("Example posting to SparkFun's data channel");
  
  //pinMode(2, INPUT);
  //pinMode(3, INPUT);
  //while(1);
  
  //Start configuration of shield with baudrate.
  //For http uses it is recommended to use 4800 or slower.
  Serial.println("Starting module");
  if (gsm.begin(2400))
  {
    Serial.println("Module online!");
    module_connected = true;
  } 
  else 
  {
    Serial.println("Module failed to connect. Check that you have external power.");
  }

  if(module_connected) {
    //Send an SMS after module connects
    //if (sms.SendSMS("3032850979", "Hello cellular world"))
    //  Serial.println("\nSMS sent OK");
  }

}

void loop()
{
  if(module_connected) {
    //Read if there are messages on SIM card and print them.

#define PUBLIC_KEY "lzonOvxpqwUmEj8aR13o"
#define PRIVATE_KEY  "ElnmvD2EePCvnxVya57g"
    
    char* server = "54.86.132.254"; //data.sparkfun.com
    int port = 80; //For HTTP action, use port 80
    
    //Put together the HTML link we want to post to the datachannel
    //Example: /input/lzonOvxpqwUmEj8aR13o?private_key=ElnmvD2EePCvnxVya57g&temp=12
    char path[100];
    strcpy(path,"/input/");
    strcat(path, PUBLIC_KEY);
    strcat(path, "?private_key=");
    strcat(path, PRIVATE_KEY);
    strcat(path, "&temp=15");
    //"temp=12";
    
    Serial.print("path: ");
    Serial.println(path);

    int result_len = 100;
    char results[result_len];

    if(inet.httpPOST(server, port, path, results, result_len)) //Push this information to the data channel
    {
      Serial.print("Result len: ");
      Serial.println(result_len, DEC);

      Serial.print("Result: ");
      Serial.println(results);
    }
    else
    {
      Serial.println("Error received");      
    }
    
    while(1);

    delay(1000);
  }
}

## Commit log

2014-09-17 Corrected +/- on battery connector
    [MG2639 Cellular Shield.brd, MG2639 Cellular Shield.sch]
2014-10-05 Prelim firmware. Works for certain features.
    [MG2639 Cellular Shield.brd, MG2639 Cellular Shield.sch]
2014-10-06 Adding PDF of schematic
2014-10-20 Filling out info in header
    Removed mentions to the battery management IC
    Added info from schematic on Jumpers
    Added note on external power requirement
2014-10-31 Add silk labels to pins/jumpers. Add FTDI header. Remove SYSRST circuit. Reconfiguring jumpers. Removed USB connector, broke USB pins out to headers.
    [MG2639 Cellular Shield.brd, MG2639 Cellular Shield.sch]
2014-10-31 adding pdf schematic of v10
2014-11-03 re-routing around TXB0108, cleaning up some silk.
    [MG2639 Cellular Shield.brd, MG2639 Cellular Shield.sch]
2014-11-03 adding 22 ohm resistors to D+/D-. placing more vias around vreg.
    [MG2639 Cellular Shield.brd, MG2639 Cellular Shield.sch]
2014-11-03 rearranging LEDs - moving GPS LED up with others.
    [MG2639 Cellular Shield.brd, MG2639 Cellular Shield.sch]
2014-11-04 Switching TXB0108 to a TXB0104. Breaking out I2C pins, 2.8V. Fixing some silk.
    [MG2639 Cellular Shield.brd, MG2639 Cellular Shield.sch]
2014-11-04 Updating Board Layout image
2014-11-04 updating PDF schematic to match current board file
2015-01-09 Routing UART1 to FTDI header instead of GPS. Adding TP's. Fixing silk. Routing out GPS battery pull-out area.
    [MG2639 Cellular Shield.brd, MG2639 Cellular Shield.sch]
2015-01-13 Adding stand-off holes. Moving GPS UART to pins 8/9 (better support for faster buad rates). Adding jumpers to select hardware UART for GPS too.
    [MG2639 Cellular Shield.brd, MG2639 Cellular Shield.sch]
2015-01-13 Defaulting TXB0104 HV to 5V. Fixing connector names. Adding measures.
    [MG2639 Cellular Shield.brd, MG2639 Cellular Shield.sch]
2015-01-14 Adding production ID to MG2639 Cell module.
    [MG2639 Cellular Shield.brd, MG2639 Cellular Shield.sch]
2015-01-15 Adding test point to 3.8V bus.
    [MG2639 Cellular Shield.brd, MG2639 Cellular Shield.sch]
2015-01-15 Re-routing GTX-HV to D8 on the Arduino.
    [MG2639 Cellular Shield.brd, MG2639 Cellular Shield.sch]
2015-01-15 Cleaning up nets around Arduino Shield connector (removing stubs).
    [MG2639 Cellular Shield.brd, MG2639 Cellular Shield.sch]
2015-01-20 Switching GPS fix indicator LED to yellow.
    [MG2639 Cellular Shield.brd, MG2639 Cellular Shield.sch]
2015-01-21 moved board fiducial
    [MG2639 Cellular Shield.brd]
2015-01-21 created panel v11
    [MG2639_Cellular_Shield_Panel-v11.brd]
2015-04-07 Updating schematic PDF. Moving Eagle library.
    - Deleted library folder to avoid confusion with incoming libraries folder
    (Arduino library).
    - Deleted MG2639 Cellular Shield.txt
2015-04-07 Initial commit of SparkFun MG2639 Arduino library
2015-04-07 Renaming directories to match template.
    Removing "Marked" datasheets.
    [MG2639 Cellular Shield.brd, MG2639 Cellular Shield.sch]
2015-04-07 Updating README.md. Removing unlinked images.
    [MG2639_Cellular_Shield_Panel-v11.brd]
2015-05-07 Squashed 'Libraries/Arduino/' content from commit 4f0d0cb
    git-subtree-dir: Libraries/Arduino
    git-subtree-split: 4f0d0cb55587b8f950655b3f631f1b648792c77b
2016-03-29 Updating LiPo connector value to DNP
    [MG2639 Cellular Shield.brd, MG2639 Cellular Shield.sch]

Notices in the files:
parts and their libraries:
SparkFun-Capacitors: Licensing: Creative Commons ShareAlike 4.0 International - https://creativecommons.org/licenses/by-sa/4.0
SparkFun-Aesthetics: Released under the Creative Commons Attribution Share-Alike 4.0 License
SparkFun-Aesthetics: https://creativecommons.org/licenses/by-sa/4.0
